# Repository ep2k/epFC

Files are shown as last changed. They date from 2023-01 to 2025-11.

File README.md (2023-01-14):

# epFC - Famicom Emulator on an FPGA

epFC is an implementation of Nintendo's __Family Computer__ (__Nintendo Entertainment System__) written in SystemVerilog.
It works on an FPGA board with a board for connection to Famicom cartridges.

It has no built-in mappers except for NROM, and can basically only operate in real-time communication with cartridges.

The operation has been confirmed with Terasic DE0-CV Board.

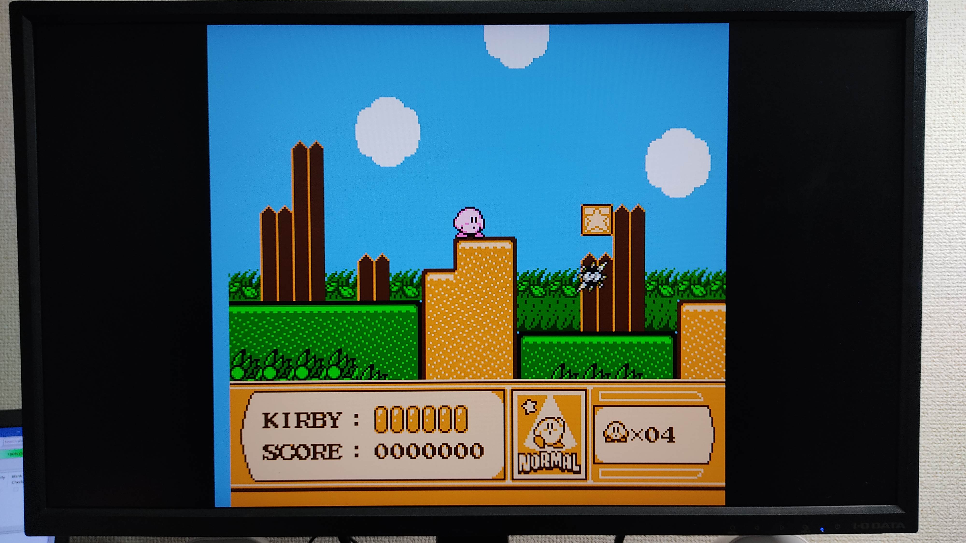
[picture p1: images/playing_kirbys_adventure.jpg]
Playing Kirby's Adventure Playing Kirby's Adventure (1993, HAL Laboratory)


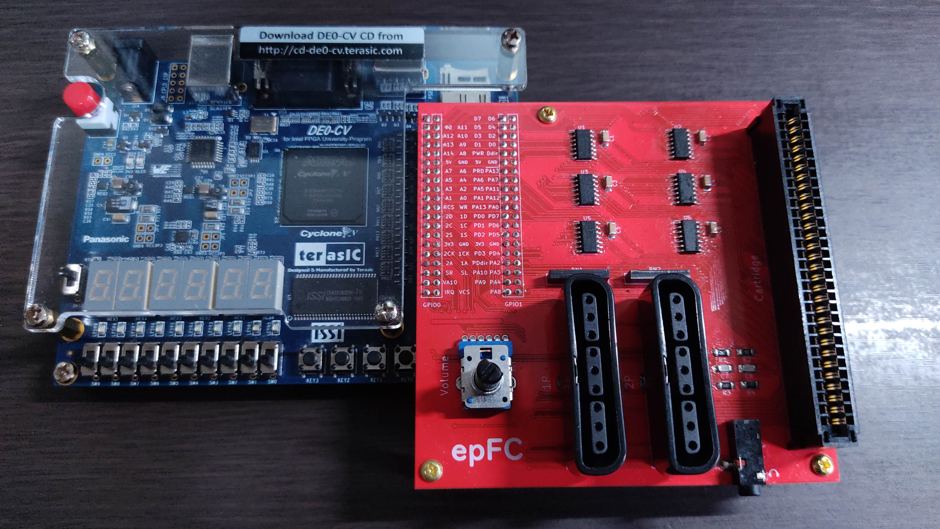
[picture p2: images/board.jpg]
Terasic DE0-CV and my own board for connecting the FPGA and Famicom cartridges


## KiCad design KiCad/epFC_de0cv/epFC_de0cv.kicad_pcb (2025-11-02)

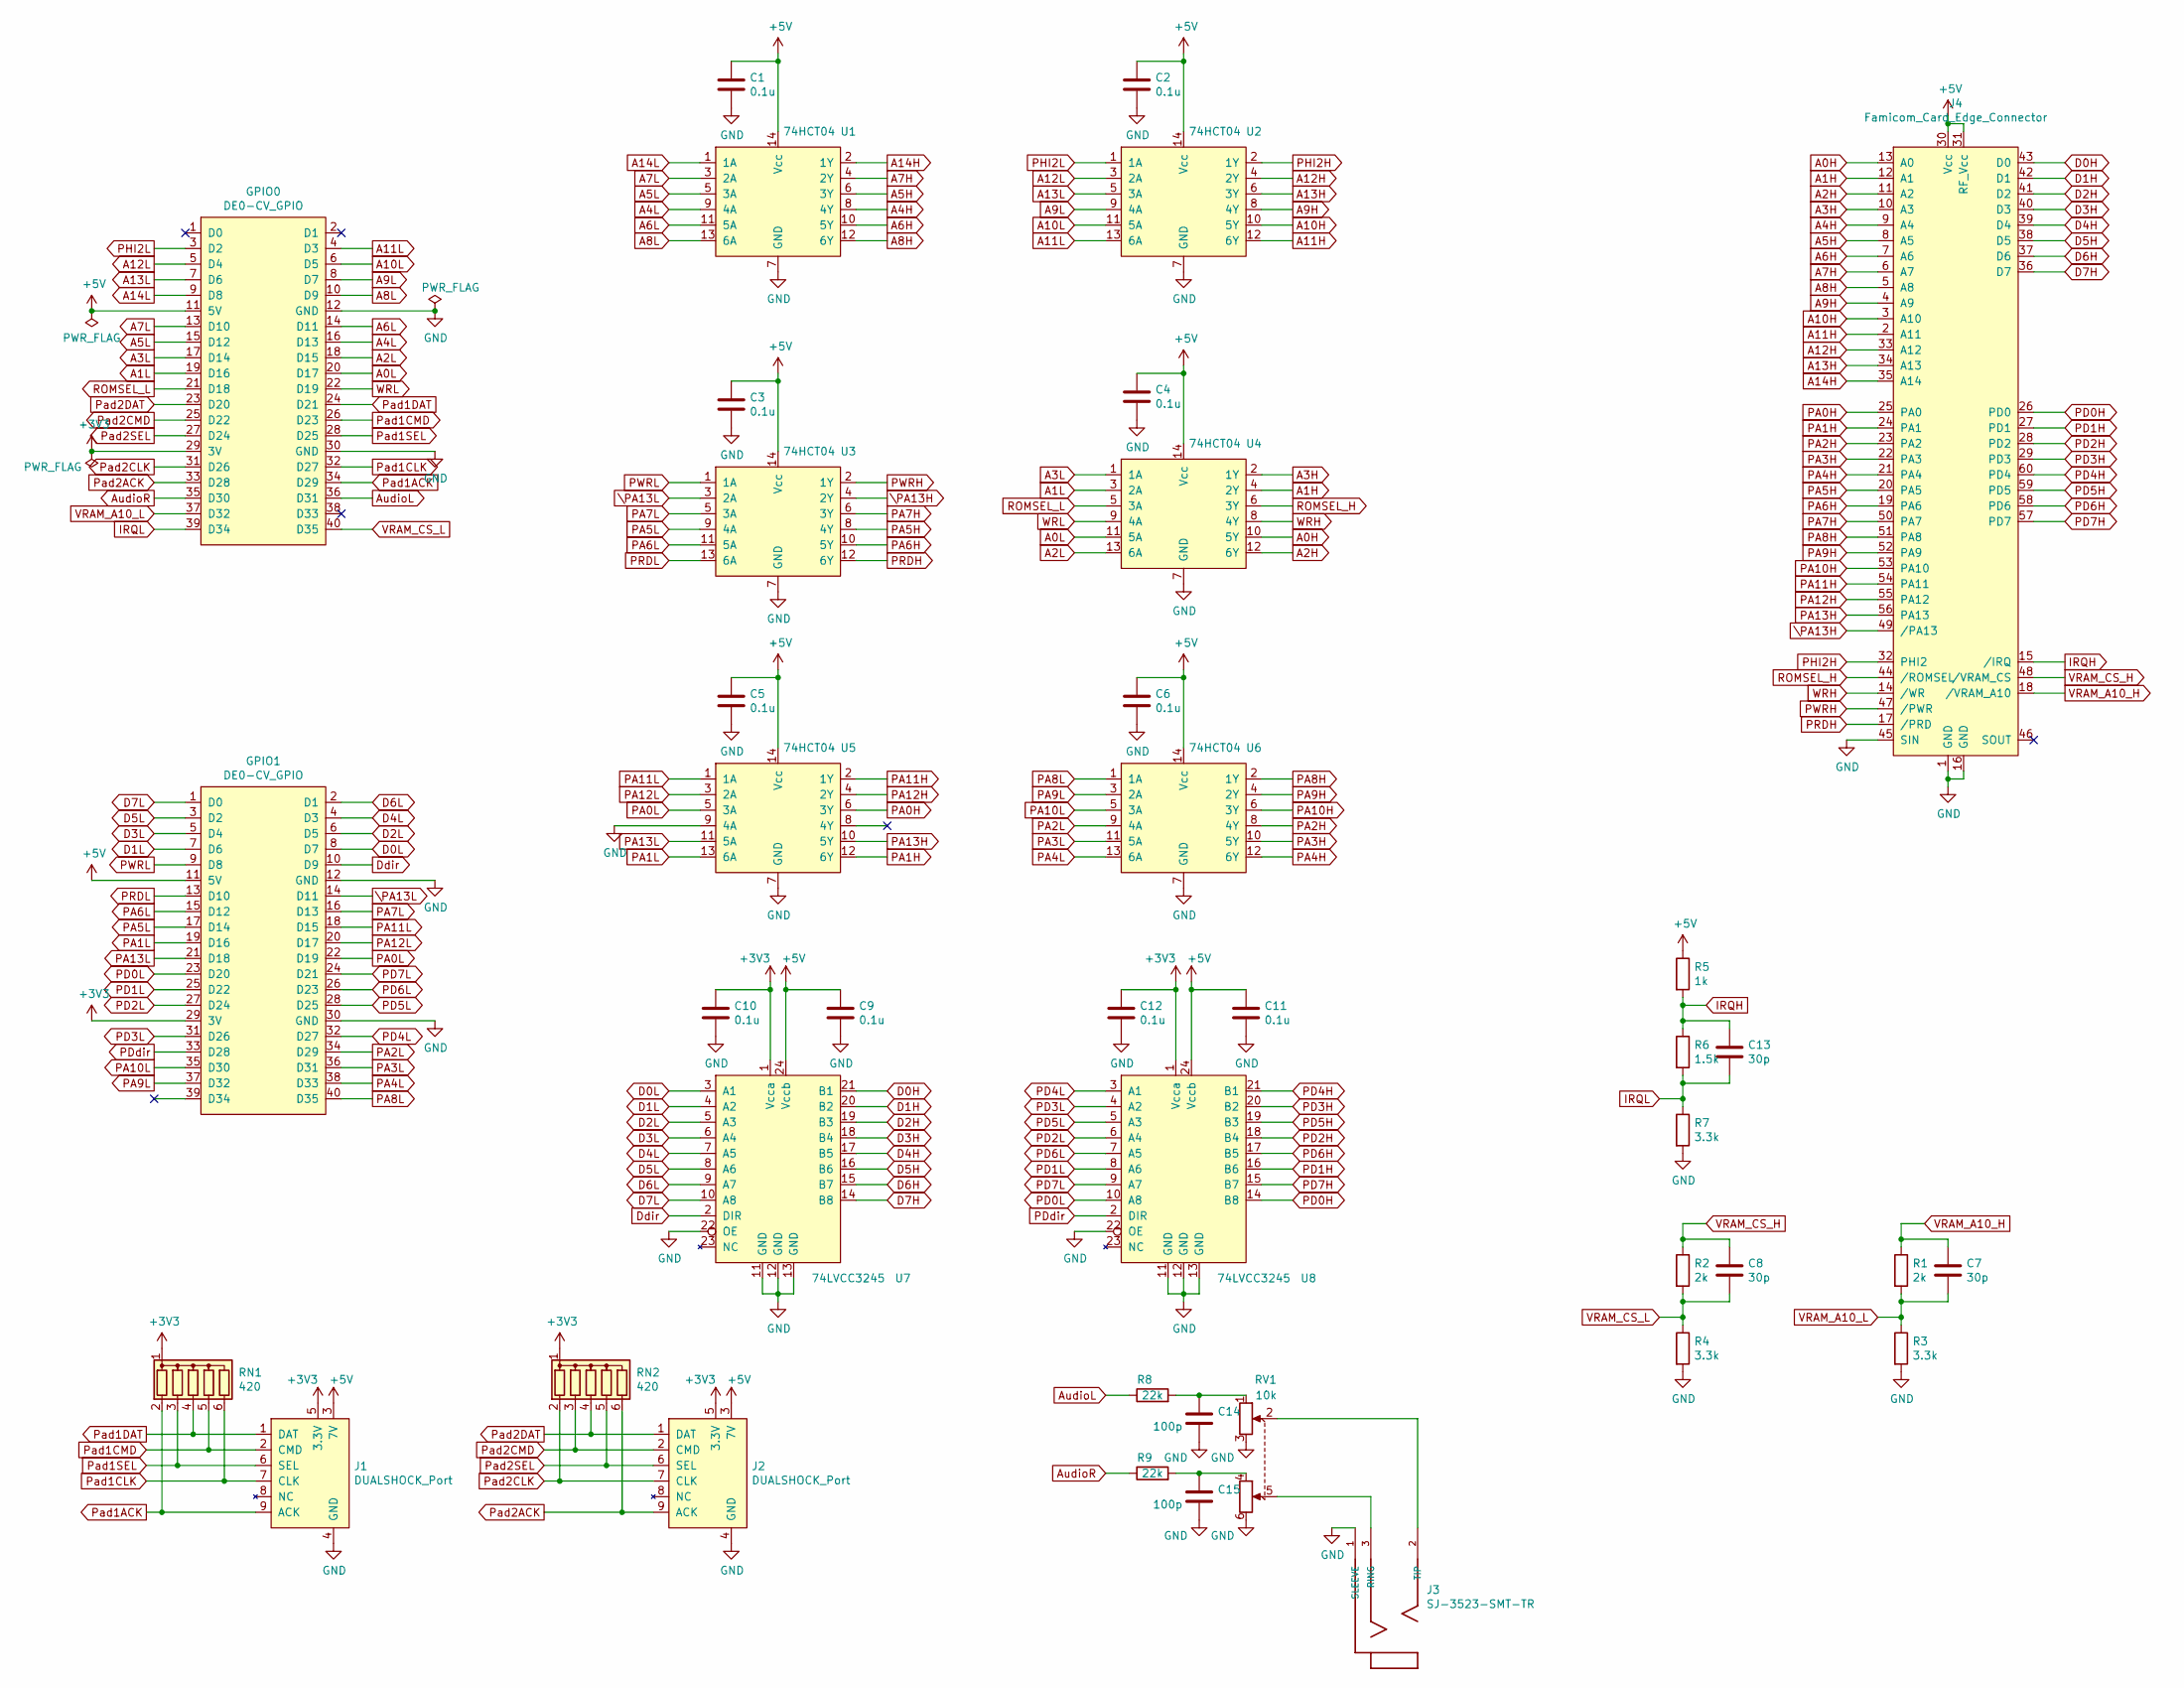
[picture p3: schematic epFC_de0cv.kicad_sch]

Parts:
C1, C2, C3, C4, C5, C6, C9, C10, C11, C12: 0.1u; C_1206_3216Metric_Pad1.33x1.80mm_HandSolder
C7, C8, C13: 30p; C_1206_3216Metric_Pad1.33x1.80mm_HandSolder
C14, C15: 100p; C_1206_3216Metric_Pad1.33x1.80mm_HandSolder
GPIO0, GPIO1: DE0-CV_GPIO; PinSocket_2x20_P2.54mm_Vertical_Back
J1, J2: DUALSHOCK_Port
J3: SJ-3523-SMT-TR; CUI_SJ-3523-SMT-TR
J4: Famicom_Card_Edge_Connector
R1, R2: 2k; R_1206_3216Metric_Pad1.30x1.75mm_HandSolder
R3, R4, R7: 3.3k; R_1206_3216Metric_Pad1.30x1.75mm_HandSolder
R5: 1k; R_1206_3216Metric_Pad1.30x1.75mm_HandSolder
R6: 1.5k; R_1206_3216Metric_Pad1.30x1.75mm_HandSolder
R8, R9: 22k; R_1206_3216Metric_Pad1.30x1.75mm_HandSolder
RN1, RN2: 420; R_Array_SIP6
RV1: 10k; Potentiometer_Bourns_PTV112
U1, U2, U3, U4, U5, U6: 74HCT04; SOIC-14_3.9x8.7mm_P1.27mm
U7, U8: 74LVCC3245; SO-24_5.3x15mm_P1.27mm

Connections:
+3V3: C10.1, C12.1, GPIO0.29 (3V), GPIO1.29 (3V), J1.5 (3.3V), J2.5 (3.3V), RN1.1 (common), RN2.1 (common), U7.1 (Vcca), U8.1 (Vcca)
+5V: C1.1, C2.1, C3.1, C4.1, C5.1, C6.1, C9.1, C11.1, GPIO0.11 (5V), GPIO1.11 (5V), J1.3 (7V), J2.3 (7V), J4.30 (Vcc), J4.31 (RF_Vcc), R5.1, U1.14 (Vcc), U2.14 (Vcc), U3.14 (Vcc), U4.14 (Vcc), U5.14 (Vcc), U6.14 (Vcc), U7.24 (Vccb), U8.24 (Vccb)
A0H: J4.13 (A0), U4.10 (5Y)
A0L: GPIO0.20 (D17), U4.11 (5A)
A1H: J4.12 (A1), U4.4 (2Y)
A1L: GPIO0.19 (D16), U4.3 (2A)
A2H: J4.11 (A2), U4.12 (6Y)
A2L: GPIO0.18 (D15), U4.13 (6A)
A3H: J4.10 (A3), U4.2 (1Y)
A3L: GPIO0.17 (D14), U4.1 (1A)
A4H: J4.9 (A4), U1.8 (4Y)
A4L: GPIO0.16 (D13), U1.9 (4A)
A5H: J4.8 (A5), U1.6 (3Y)
A5L: GPIO0.15 (D12), U1.5 (3A)
A6H: J4.7 (A6), U1.10 (5Y)
A6L: GPIO0.14 (D11), U1.11 (5A)
A7H: J4.6 (A7), U1.4 (2Y)
A7L: GPIO0.13 (D10), U1.3 (2A)
A8H: J4.5 (A8), U1.12 (6Y)
A8L: GPIO0.10 (D9), U1.13 (6A)
A9H: J4.4 (A9), U2.8 (4Y)
A9L: GPIO0.8 (D7), U2.9 (4A)
A10H: J4.3 (A10), U2.10 (5Y)
A10L: GPIO0.6 (D5), U2.11 (5A)
A11H: J4.2 (A11), U2.12 (6Y)
A11L: GPIO0.4 (D3), U2.13 (6A)
A12H: J4.33 (A12), U2.4 (2Y)
A12L: GPIO0.5 (D4), U2.3 (2A)
A13H: J4.34 (A13), U2.6 (3Y)
A13L: GPIO0.7 (D6), U2.5 (3A)
A14H: J4.35 (A14), U1.2 (1Y)
A14L: GPIO0.9 (D8), U1.1 (1A)
AudioL: GPIO0.36 (D31), R8.1
AudioR: GPIO0.35 (D30), R9.1
D0H: J4.43 (D0), U7.21 (B1)
D0L: GPIO1.8 (D7), U7.3 (A1)
D1H: J4.42 (D1), U7.20 (B2)
D1L: GPIO1.7 (D6), U7.4 (A2)
D2H: J4.41 (D2), U7.19 (B3)
D2L: GPIO1.6 (D5), U7.5 (A3)
D3H: J4.40 (D3), U7.18 (B4)
D3L: GPIO1.5 (D4), U7.6 (A4)
D4H: J4.39 (D4), U7.17 (B5)
D4L: GPIO1.4 (D3), U7.7 (A5)
D5H: J4.38 (D5), U7.16 (B6)
D5L: GPIO1.3 (D2), U7.8 (A6)
D6H: J4.37 (D6), U7.15 (B7)
D6L: GPIO1.2 (D1), U7.9 (A7)
D7H: J4.36 (D7), U7.14 (B8)
D7L: GPIO1.1 (D0), U7.10 (A8)
Ddir: GPIO1.10 (D9), U7.2 (DIR)
GND: C1.2, C2.2, C3.2, C4.2, C5.2, C6.2, C9.2, C10.2, C11.2, C12.2, C14.2, C15.2, GPIO0.12 (GND), GPIO0.30 (GND), GPIO1.12 (GND), GPIO1.30 (GND), J1.4 (GND), J2.4 (GND), J3.1 (SLEEVE), J4.1 (GND), J4.16 (GND), J4.45 (SIN), R3.2, R4.2, R7.2, RV1.3, RV1.6, U1.7 (GND), U2.7 (GND), U3.7 (GND), U4.7 (GND), U5.7 (GND), U5.9 (4A), U6.7 (GND), U7.11 (GND), U7.12 (GND), U7.13 (GND), U7.22 (OE), U8.11 (GND), U8.12 (GND), U8.13 (GND), U8.22 (OE)
IRQH: C13.1, J4.15 (/IRQ), R5.2, R6.1
IRQL: C13.2, GPIO0.39 (D34), R6.2, R7.1
unnamed: C14.1, R8.2, RV1.1
unnamed: C15.1, R9.2, RV1.4
unnamed: J3.3 (RING), RV1.5
unnamed: J3.2 (TIP), RV1.2
PA0H: J4.25 (PA0), U5.6 (3Y)
PA0L: GPIO1.22 (D19), U5.5 (3A)
PA1H: J4.24 (PA1), U5.12 (6Y)
PA1L: GPIO1.19 (D16), U5.13 (6A)
PA2H: J4.23 (PA2), U6.8 (4Y)
PA2L: GPIO1.34 (D29), U6.9 (4A)
PA3H: J4.22 (PA3), U6.10 (5Y)
PA3L: GPIO1.36 (D31), U6.11 (5A)
PA4H: J4.21 (PA4), U6.12 (6Y)
PA4L: GPIO1.38 (D33), U6.13 (6A)
PA5H: J4.20 (PA5), U3.8 (4Y)
PA5L: GPIO1.17 (D14), U3.9 (4A)
PA6H: J4.19 (PA6), U3.10 (5Y)
PA6L: GPIO1.15 (D12), U3.11 (5A)
PA7H: J4.50 (PA7), U3.6 (3Y)
PA7L: GPIO1.16 (D13), U3.5 (3A)
PA8H: J4.51 (PA8), U6.2 (1Y)
PA8L: GPIO1.40 (D35), U6.1 (1A)
PA9H: J4.52 (PA9), U6.4 (2Y)
PA9L: GPIO1.37 (D32), U6.3 (2A)
PA10H: J4.53 (PA10), U6.6 (3Y)
PA10L: GPIO1.35 (D30), U6.5 (3A)
PA11H: J4.54 (PA11), U5.2 (1Y)
PA11L: GPIO1.18 (D15), U5.1 (1A)
PA12H: J4.55 (PA12), U5.4 (2Y)
PA12L: GPIO1.20 (D17), U5.3 (2A)
PA13H: J4.56 (PA13), U5.10 (5Y)
PA13L: GPIO1.21 (D18), U5.11 (5A)
PD0H: J4.26 (PD0), U8.14 (B8)
PD0L: GPIO1.23 (D20), U8.10 (A8)
PD1H: J4.27 (PD1), U8.16 (B6)
PD1L: GPIO1.25 (D22), U8.8 (A6)
PD2H: J4.28 (PD2), U8.18 (B4)
PD2L: GPIO1.27 (D24), U8.6 (A4)
PD3H: J4.29 (PD3), U8.20 (B2)
PD3L: GPIO1.31 (D26), U8.4 (A2)
PD4H: J4.60 (PD4), U8.21 (B1)
PD4L: GPIO1.32 (D27), U8.3 (A1)
PD5H: J4.59 (PD5), U8.19 (B3)
PD5L: GPIO1.28 (D25), U8.5 (A3)
PD6H: J4.58 (PD6), U8.17 (B5)
PD6L: GPIO1.26 (D23), U8.7 (A5)
PD7H: J4.57 (PD7), U8.15 (B7)
PD7L: GPIO1.24 (D21), U8.9 (A7)
PDdir: GPIO1.33 (D28), U8.2 (DIR)
PHI2H: J4.32 (PHI2), U2.2 (1Y)
PHI2L: GPIO0.3 (D2), U2.1 (1A)
PRDH: J4.17 (/PRD), U3.12 (6Y)
PRDL: GPIO1.13 (D10), U3.13 (6A)
PWRH: J4.47 (/PWR), U3.2 (1Y)
PWRL: GPIO1.9 (D8), U3.1 (1A)
Pad1ACK: GPIO0.34 (D29), J1.9 (ACK), RN1.2 (R1)
Pad1CLK: GPIO0.32 (D27), J1.7 (CLK), RN1.6 (R5)
Pad1CMD: GPIO0.26 (D23), J1.2 (CMD), RN1.5 (R4)
Pad1DAT: GPIO0.24 (D21), J1.1 (DAT), RN1.4 (R3)
Pad1SEL: GPIO0.28 (D25), J1.6 (SEL), RN1.3 (R2)
Pad2ACK: GPIO0.33 (D28), J2.9 (ACK), RN2.6 (R5)
Pad2CLK: GPIO0.31 (D26), J2.7 (CLK), RN2.2 (R1)
Pad2CMD: GPIO0.25 (D22), J2.2 (CMD), RN2.3 (R2)
Pad2DAT: GPIO0.23 (D20), J2.1 (DAT), RN2.4 (R3)
Pad2SEL: GPIO0.27 (D24), J2.6 (SEL), RN2.5 (R4)
ROMSEL_H: J4.44 (/ROMSEL), U4.6 (3Y)
ROMSEL_L: GPIO0.21 (D18), U4.5 (3A)
VRAM_A10_H: C7.1, J4.18 (/VRAM_A10), R1.1
VRAM_A10_L: C7.2, GPIO0.37 (D32), R1.2, R3.1
VRAM_CS_H: C8.1, J4.48 (/VRAM_CS), R2.1
VRAM_CS_L: C8.2, GPIO0.40 (D35), R2.2, R4.1
WRH: J4.14 (/WR), U4.8 (4Y)
WRL: GPIO0.22 (D19), U4.9 (4A)
\PA13H: J4.49 (/PA13), U3.4 (2Y)
\PA13L: GPIO1.14 (D11), U3.3 (2A)

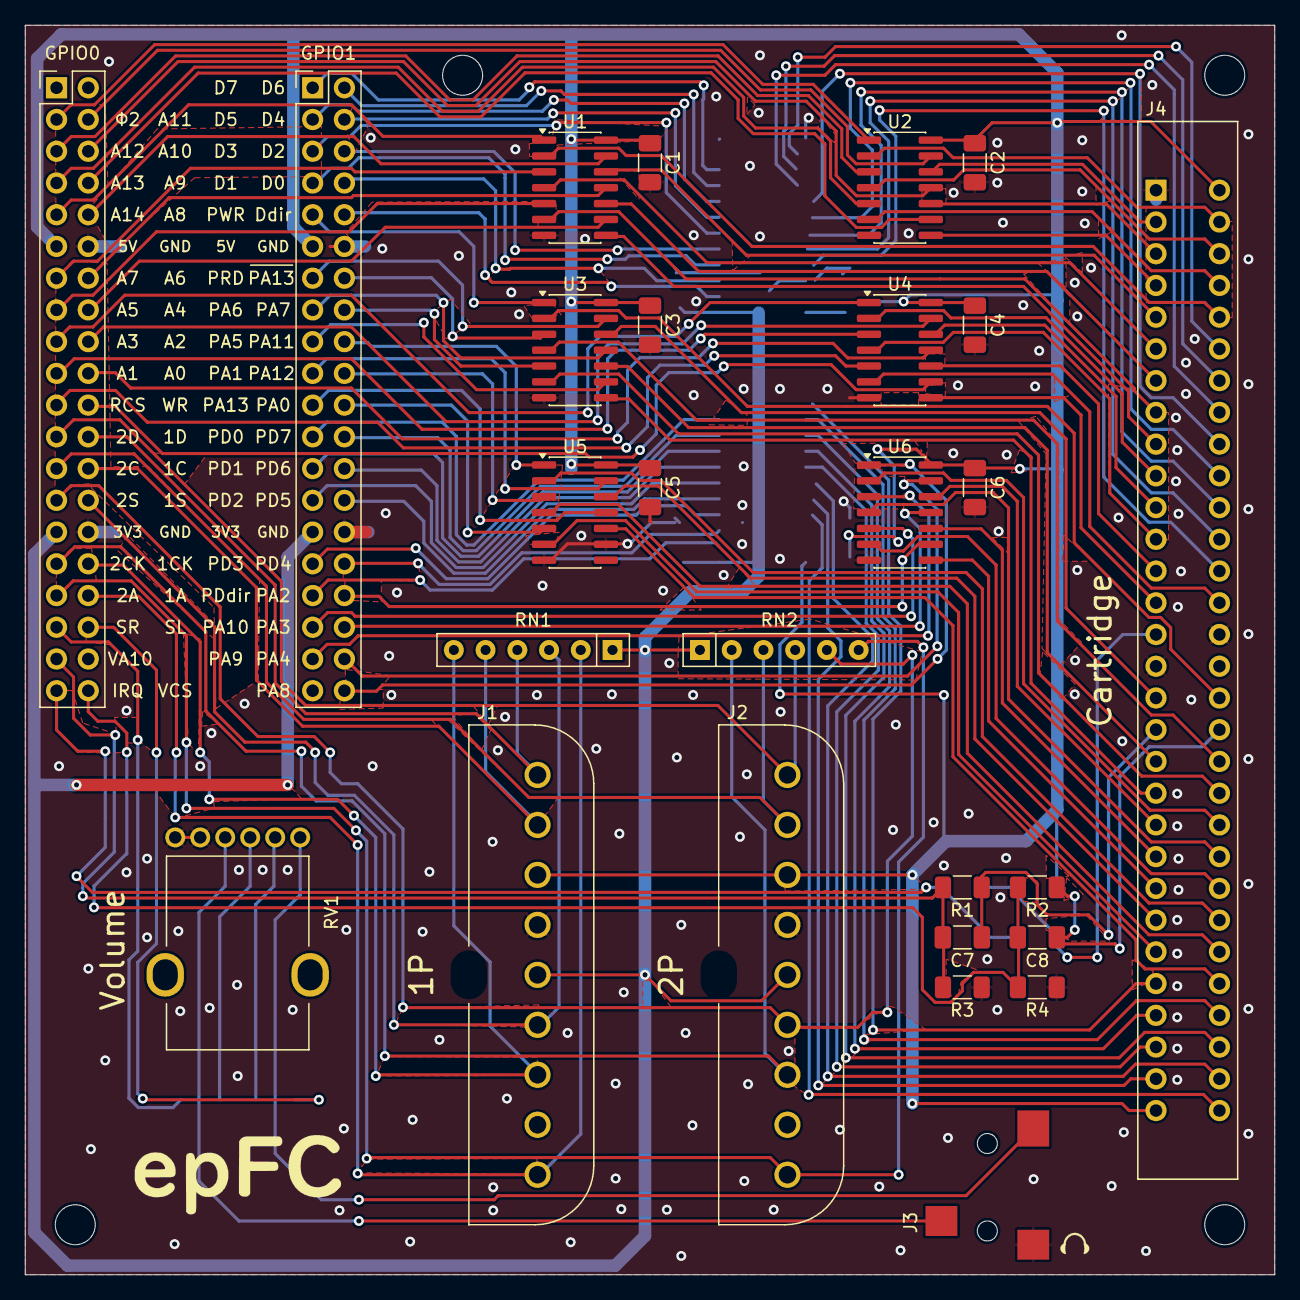
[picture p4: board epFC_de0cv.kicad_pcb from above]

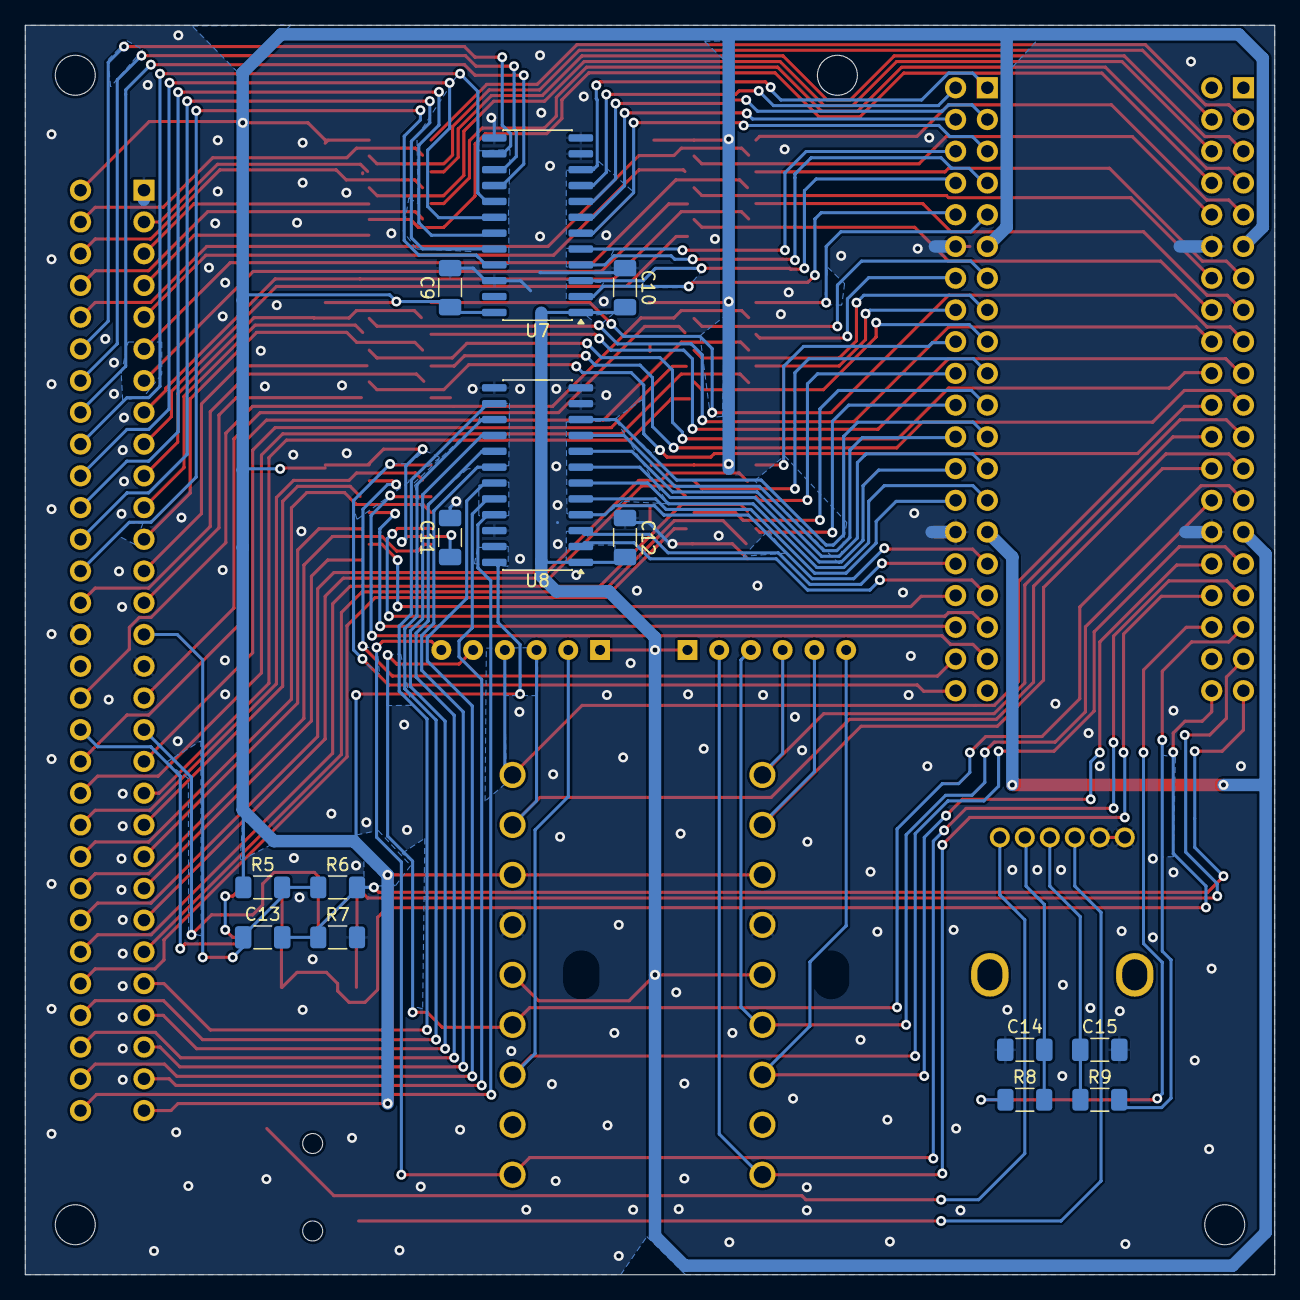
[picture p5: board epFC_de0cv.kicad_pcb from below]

Board: 2 copper layers, 100.0 x 100.0 mm, 41 parts (14 on the bottom side), 129 nets.

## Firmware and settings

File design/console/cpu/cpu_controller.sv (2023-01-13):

module cpu_controller (
    input  logic clk,
    input  logic cpu_en,
    input  logic [7:0] op,
    input  logic [7:0] p,
    input  logic reset,
    input  logic nmi,
    input  logic irq,
    input  logic [3:0] alu_flgs,
    input  logic pcl_m,
    input  logic al_m,

    output logic [2:0] addr_high_src,
    output logic [1:0] addr_low_src,
    output logic mem_read,
    output logic mem_write,

    output logic [3:0] alu_a_src,
    output logic [2:0] alu_b_src,
    output logic [3:0] alu_control,

    output logic a_src,
    output logic x_src,
    output logic y_src,
    output logic s_src,
    output logic p_src,
    output logic pcl_src,
    output logic pch_src,
    output logic [1:0] al_src,
    output logic ah_src,
    output logic data_src,

    output logic [7:0] p_next,
    output logic [1:0] val_select,

    output logic a_write,
    output logic x_write,
    output logic y_write,
    output logic s_write,
    output logic pcl_write,
    output logic pch_write,
    output logic op_write,
    output logic al_write,
    output logic ah_write,
    output logic data_write,
    output logic [7:0] p_write,

    output logic pc_inc,
    output logic s_inc,
    output logic s_dec
);

    localparam C = 0, Z = 1, I = 2, D = 3, B = 4, V = 6, N = 7; // P

    typedef enum logic [3:0] {
        S0, S1, S2, S3, S4, S5, S6,
        SI1, SI2, SI3, SI4, SI5, SI6
    } statetype;

    statetype state = SI1;
    statetype next_state;

    always_ff @(posedge clk) begin
        if (reset) begin
            state <= SI1;
        end else if (cpu_en) begin
            state <= next_state; 
        end
    end

    // 割り込みフラグ

    logic reset_flg = 1'b1;
    logic nmi_flg, brk_flg;
    logic nmi_prev;
    logic intflg_clear, brk_set, brk_clear;

    always_ff @(posedge clk) begin
        if (reset) begin
            reset_flg <= 1'b1;
            nmi_flg <= 1'b0;
        end else if (cpu_en) begin
            if (intflg_clear) begin
                nmi_flg <= 1'b0;
                reset_flg <= 1'b0;
            end else begin
                nmi_flg <= nmi_flg | ((~nmi_prev) & nmi); // nmiが0→1のとき1
            end
        end
    end

    always_ff @(posedge clk) begin
        if (cpu_en) begin
            nmi_prev <= nmi;
        end
    end

    always_ff @(posedge clk) begin
        if (reset) begin
            brk_flg <= 1'b0;
        end else if (cpu_en) begin
            if (brk_clear) begin
                brk_flg <= 1'b0;
            end else if (brk_set) begin
                brk_flg <= 1'b1;
            end
        end
    end

    // コントロール
    always_comb begin
        
        // ### 既定値 ####################################

        next_state = S0;

        intflg_clear = 1'b0;
        brk_set = 1'b0;
        brk_clear = 1'b0;

        alu_a_src = 4'bxxxx; // A
        alu_b_src = 3'b000; // 0
        alu_control = 4'b0000; // ADD

        addr_high_src = 3'b000; // PCH
        addr_low_src = 2'b00; // PCL

        p_next = {alu_flgs[3:2], 4'b0000, alu_flgs[1:0]};
        p_src = 1'b0; // コントローラー

        a_src = 1'bx;
        x_src = 1'bx;
        y_src = 1'bx;
        s_src = 1'bx;
        pch_src = 1'bx;
        pcl_src = 1'bx;
        al_src = 2'bxx;
        ah_src = 1'bx;
        data_src = 1'bx;

        val_select = 2'bxx;

        mem_write = 1'b0;
        mem_read = 1'b0;
        a_write = 1'b0;
        x_write = 1'b0;
        y_write = 1'b0;
        s_write = 1'b0;
        pcl_write = 1'b0;
        pch_write = 1'b0;
        op_write = 1'b0;
        al_write = 1'b0;
        ah_write = 1'b0;
        data_write = 1'b0;
        p_write = 8'h00;

        pc_inc = 1'b0;
        s_inc = 1'b0;
        s_dec = 1'b0;

        // ###################################################

        if (state == S0) begin
            
            if (nmi_flg | (irq & ~p[I])) begin // 割り込み

                if (nmi_flg) begin
                    val_select = 2'b00; // $FA
                end else begin
                    val_select = 2'b10; // $FE
                end
                
                al_src = 2'b10; // VAL
                al_write = 1'b1;

                p_next[B] = 1'b0; p_write[B] = 1'b1; // Bクリア

                next_state = SI1;

            end else begin
                op_write = 1'b1;
                pc_inc = 1'b1;
                mem_read = 1'b1;
                next_state = S1;
            end

        end else if (state == SI1) begin

            if (brk_flg & (nmi_flg | irq)) begin // BRKスキップ
                brk_clear = 1'b1;
                next_state = S0;
            end else begin
                next_state = SI2;
            end

        end else if (state == SI2 || state == SI3) begin
            
            // [01, S] <- PCH/PCL
            // S--

            addr_high_src = 3'b101; // 01
            addr_low_src = 2'b10; // S
            alu_a_src = (state == SI2) ? 4'b0101 : 4'b0110; // PCH/PCL
            mem_write = ~reset_flg; // RESETのときは書き込まない
            s_dec = 1'b1;

            if (brk_flg & (nmi_flg | irq)) begin // BRKスキップ
                brk_clear = 1'b1;
                next_state = S0;
            end else begin
                next_state = (state == SI2) ? SI3 : SI4;
            end

        end else if (state == SI4) begin
            
            // [01, S] <- P
            // S--

            addr_high_src = 3'b101; // 01
            addr_low_src = 2'b10; // S
            alu_a_src = 4'b0100; // P
            mem_write = ~reset_flg; // RESETのときは書き込まない
            s_dec = 1'b1;
            next_state = SI5;

        end else if (state == SI5) begin
            
            // PCL <- [FF, AL]
            // AL <- AL+1

            addr_high_src = 3'b110; // FF
            addr_low_src = 2'b01; // AL
            mem_read = 1'b1;
            pcl_src = 1'b1; // RD
            pcl_write = 1'b1;

            alu_a_src = 4'b1000; // AL
            alu_b_src = 3'b001; // 1
            al_src = 1'b0; // alu_y
            al_write = 1'b1;

            next_state = SI6;

        end else if (state == SI6) begin
            
            // PCH <- [FF, AL]

            addr_high_src = 3'b110; // FF
            addr_low_src = 2'b01; // AL
            mem_read = 1'b1;
            pch_src = 1'b1; // RD
            pch_write = 1'b1;

            p_next[I] = 1'b1; p_write[I] = 1'b1; // Iセット

            brk_clear = 1'b1;
            intflg_clear = 1'b1;
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

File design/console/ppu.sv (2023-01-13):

module ppu (
    input  logic clk,               // ppu_clk
    input  logic cpu_en,
    input  logic reset,

    input  logic [2:0] opcode,      // cpu_addr[2:0]
    input  logic [7:0] wdata,
    input  logic read,
    input  logic write,
    output logic [7:0] rdata,
    output logic nmi,

    output logic [13:0] ppumap_addr,
    input  logic [7:0] ppumap_rdata,
    output logic [7:0] ppumap_wdata,
    output logic ppumap_read,
    output logic ppumap_write,

    output logic [15:0] pixel_num,
    output logic [4:0] pixel_info,
    output logic pixel_write,

    input  logic [1:0] graphic_off
);

    // ---- Register ------

    logic [14:0] vram_addr, temp_vram_addr;
    logic [2:0] fine_x = 3'b0;
    logic write_toggle = 1'b0;
    logic [7:0] vread_buffer;

    logic vblank = 1'b0;
    logic sp0_hit = 1'b0;
    logic sp_overflow = 1'b0;

    logic [7:2] ppu_ctrl = 6'h0;
    logic [7:0] ppu_mask = 8'h0;
    logic [7:0] oam_addr = 8'h0;

    logic [8:0] pixel_counter = 9'b0; // 0 ~ 340
    logic [8:0] line_counter = 9'd0; // 0 ~ 261

    logic [7:0] name_data;
    logic [7:0] attribute_data;
    logic [7:0] next_pattern_high;
    logic [7:0] next_pattern_low;
    logic [1:0] next_attribute;
    logic [15:0] pattern_shifter_low;
    logic [15:0] pattern_shifter_high;
    logic [7:0] attribute_shifter_low;
    logic [7:0] attribute_shifter_high;

    logic [5:0] sp_num = '0;
    logic [2:0] sp_second_num = '0;
    logic second_oam_full = 1'b0;
    logic sp_eval_finished = 1'b0;
    logic sp_overflow_set = 1'b0;

    // Sprite
    logic [7:0] oam[255:0];
    logic [7:0] second_oam[31:0];
    logic [7:0] sp_exist_next;
    logic [7:0] sp_exist;
    logic [7:0] sp_x[7:0];
    logic [7:0] sp_shifter_low[7:0];
    logic [7:0] sp_shifter_high[7:0];
    logic [1:0] sp_attribute[7:0];
    logic sp_priority[7:0];
    logic is_sprite0, is_sprite0_next;


    // ---- Wire ------

    logic [7:0] ppu_status;
    logic sp_8x16;
    logic not_rendering;
    logic [1:0] pixel_mask;

    logic [13:0] name_addr;
    logic [13:0] attribute_addr;
    logic [13:0] bg_pattern_addr;
    logic [13:0] sp_pattern_addr;
    logic [2:0] sp8_fine_y;
    logic [3:0] sp16_fine_y;
    logic is_sprite_n;

    logic [3:0] bg_pixel;
    logic [4:0] sprites[7:0];
    logic pixel_sp0_hit;

    logic visible_frame;
    logic pre_render_line;
    logic render_line;
    logic first_pixel_of_frame;
    logic left_edge;
    logic last_pixel_of_frame;
    logic sprite_fetch_time;
    logic sprite_evaluation_time;
    logic visible_pixel;
    logic inc_hori_pixel;
    logic inc_vert_pixel;
    logic hori_copy_pixel;
    logic vert_copy_pixel;
    logic set_vblank_pixel;
    logic clear_flgs_pixel;
    logic name_fetch_pixel;
    logic attribute_fetch_pixel;
    logic bg_low_fetch_pixel;
    logic bg_high_fetch_pixel;
    logic next_pattern_load_pixel;
    logic name_addr_pixel;
    logic attribute_addr_pixel;
    logic pattern_addr_pixel;
    logic shift_pixel;

    logic block_left;
    logic block_high;

    logic op_ppuctrl_w;
    logic op_ppumask_w;
    logic op_ppustatus_r;
    logic op_oamaddr_w;
    logic op_oamdata_r;
    logic op_oamdata_w;
    logic op_ppuscroll_w;
    logic op_ppuaddr_w;
    logic op_ppudata_r;
    logic op_ppudata_w;


    // ---- Wire Assignment ------

    // ### Output ####

    always_comb begin
        case (opcode)
            3'h2: rdata = ppu_status;
            3'h4: rdata = oam[oam_addr];
            3'h7: rdata =
                (vram_addr[14:9] == 6'h3f) ? ppumap_rdata : vread_buffer;
            default: rdata = 8'h0;
        endcase
    end

    assign nmi = vblank & ppu_ctrl[7];

    always_comb begin
        if (not_rendering) begin
            ppumap_addr = vram_addr[13:0];
        end else if (name_addr_pixel) begin
            ppumap_addr = name_addr;
        end else if (attribute_addr_pixel) begin
            ppumap_addr = attribute_addr;
        end else if (pattern_addr_pixel) begin
            ppumap_addr = sprite_fetch_time ? sp_pattern_addr : bg_pattern_addr;
        end else begin
            ppumap_addr = vram_addr[13:0];
        end
    end

    assign ppumap_wdata = wdata;
    assign ppumap_read = op_ppudata_r | name_fetch_pixel
                | attribute_fetch_pixel | bg_low_fetch_pixel | bg_high_fetch_pixel;
    assign ppumap_write = op_ppudata_w;
    
    assign pixel_num[15:8] = line_counter[7:0];
    assign pixel_num[7:0] = pixel_counter[8:0] - 9'd1;
    assign pixel_write = visible_pixel;


    // ### Basic Info ####

    assign ppu_status = {vblank, sp0_hit, sp_overflow, 5'b00000};
    assign sp_8x16 = ppu_ctrl[5];
    assign not_rendering = (ppu_mask[4:3] == 2'b00);
    assign pixel_mask = ppu_mask[4:3] & (left_edge ? ppu_mask[2:1] : 2'b11);

    // ### Fetch VRAM Address ####

    assign name_addr = {2'b10, vram_addr[11:0]};
    assign attribute_addr =
            {2'b10, vram_addr[11:10], 4'b1111, vram_addr[9:7], vram_addr[4:2]};
    assign bg_pattern_addr =
            {1'b0, ppu_ctrl[4], name_data, bg_high_fetch_pixel, vram_addr[14:12]};
    assign sp_pattern_addr = sp_8x16
        ? { 1'b0,
            second_oam[{sp_second_num, 2'b01}][0],
            second_oam[{sp_second_num, 2'b01}][7:1],
            sp16_fine_y[3], // 上半身か否か
            bg_high_fetch_pixel,
            sp16_fine_y[2:0]
        }
        : { 1'b0,
            ppu_ctrl[3],
            second_oam[{sp_second_num, 2'b01}],
            bg_high_fetch_pixel,
            sp8_fine_y
        };

    assign sp8_fine_y = second_oam[{sp_second_num, 2'b10}][7]
        ? ~(line_counter - second_oam[{sp_second_num, 2'b00}]) // 反転時はNOT
        : (line_counter - second_oam[{sp_second_num, 2'b00}]);

    assign sp16_fine_y = second_oam[{sp_second_num, 2'b10}][7]
        ? ~(line_counter - second_oam[{sp_second_num, 2'b00}]) // 反転時はNOT
        : (line_counter - second_oam[{sp_second_num, 2'b00}]);

    assign is_sprite_n = sp_8x16
        ? ((line_counter >= oam[{sp_num, 2'b00}])
            & (line_counter <= oam[{sp_num, 2'b00}] + 15)) // 8x16スプライト
        : ((line_counter >= oam[{sp_num, 2'b00}])
            & (line_counter <= oam[{sp_num, 2'b00}] + 7)); // 8x8スプライト

    // ### Pixel Info ####

    assign bg_pixel = {
        attribute_shifter_high[(3'b111 - fine_x)],
        attribute_shifter_low[(3'b111 - fine_x)],
        pattern_shifter_high[(4'hf - {1'b0, fine_x})],
        pattern_shifter_low[(4'hf - {1'b0, fine_x})]
    };

    always_comb begin
        for (int i = 0; i < 8; i++) begin
            sprites[i] = (sp_exist[i] & (sp_x[i] == 8'd0)) ? {
                        sp_priority[i],
                        sp_attribute[i],
                        sp_shifter_high[i][7],
                        sp_shifter_low[i][7]
                    } : 4'h0;
        end
    end

    // ### Timing ####
    
    assign visible_frame = (line_counter < 240);
    assign pre_render_line = (line_counter == 261);
    assign render_line = (visible_frame | pre_render_line);
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

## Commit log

2025-11-02 feat: #4 .gitignoreを追加
2025-11-02 feat: #4 カートリッジ接続基板のKiCadデータを追加
    [epFC_de0cv.kicad_pcb, epFC_de0cv.kicad_sch]
